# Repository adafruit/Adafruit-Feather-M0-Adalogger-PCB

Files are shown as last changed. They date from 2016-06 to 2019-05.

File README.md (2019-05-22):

## Adafruit Feather M0 Adalogger PCB
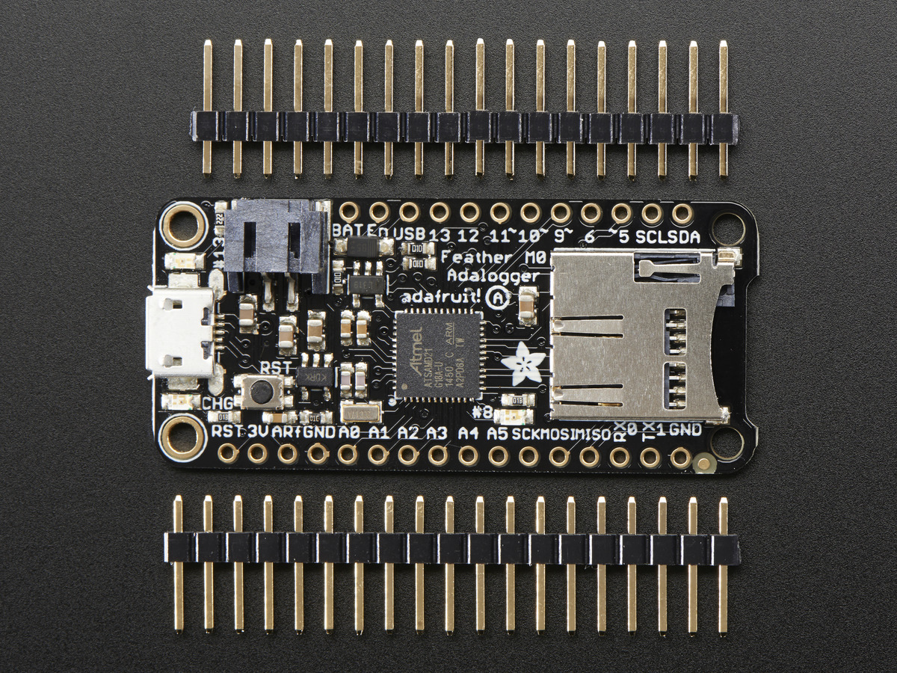
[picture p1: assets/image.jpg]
<a href="http://www.adafruit.com/products/2796"><br/>
Click here to purchase one from the Adafruit shop</a>

This is the Adafruit Feather M0 Adalogger - our take on an 'all-in-one' Cortex M0 datalogger (or data-reader) with built in USB and battery charging. Its an Adafruit Feather M0 with a microSD holder ready to rock! We have other boards in the Feather family, check'em out here

At the Feather M0's heart is an ATSAMD21G18 ARM Cortex M0 processor, clocked at 48 MHz and at 3.3V logic, the same one used in the new Arduino Zero. This chip has a whopping 256K of FLASH (8x more than the Atmega328 or 32u4) and 32K of RAM (16x as much)! This chip comes with built in USB so it has USB-to-Serial program & debug capability built in with no need for an FTDI-like chip.

PCB files for the Adafruit Feather M0 Adalogger. The format is EagleCAD schematic and board layout
- https://www.adafruit.com/product/2796

### License

Adafruit invests time and resources providing this open source design, please support Adafruit and open-source hardware by purchasing products from [Adafruit](https://www.adafruit.com)!

All text above must be included in any redistribution

Designed by Limor Fried/Ladyada for Adafruit Industries.
Creative Commons Attribution/Share-Alike, all text above must be included in any redistribution. 
See license.txt for additional information.

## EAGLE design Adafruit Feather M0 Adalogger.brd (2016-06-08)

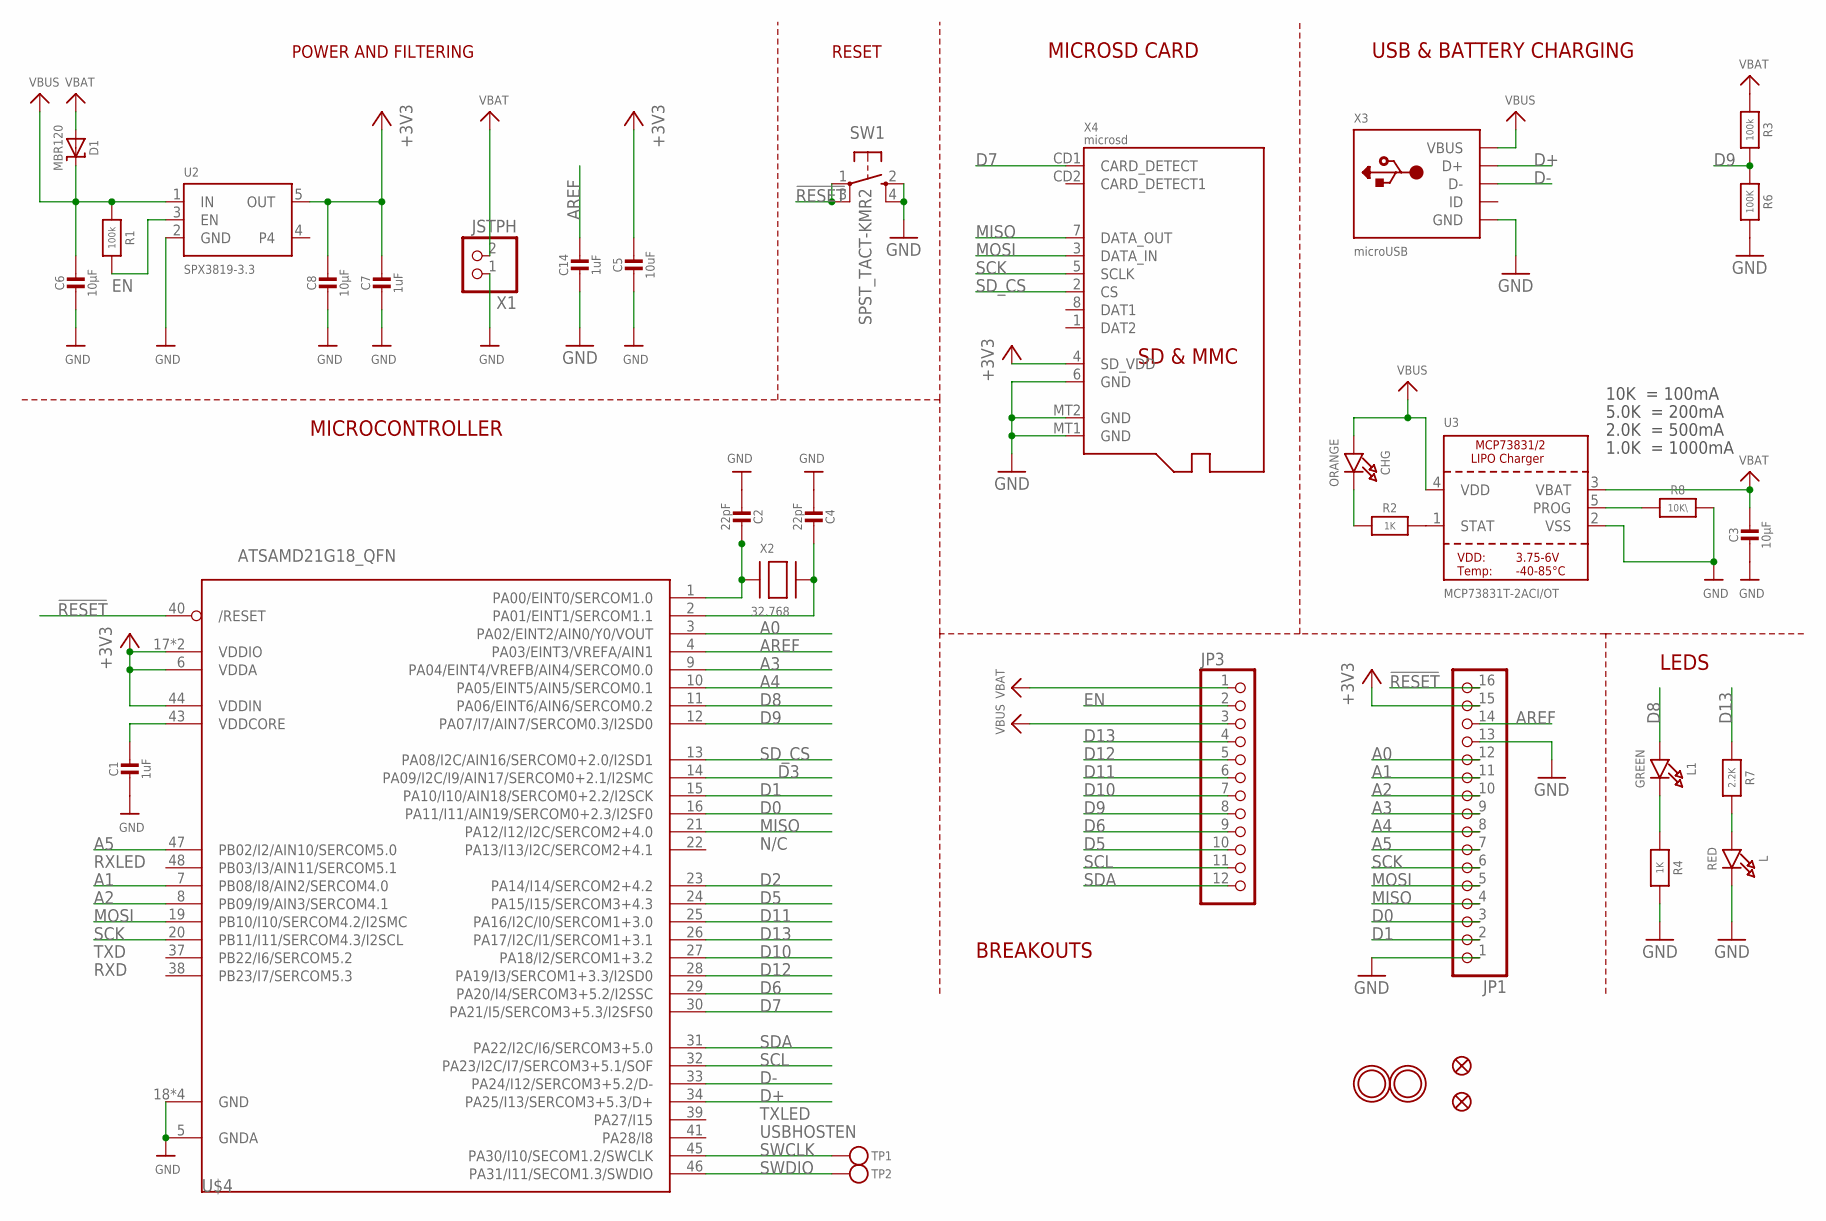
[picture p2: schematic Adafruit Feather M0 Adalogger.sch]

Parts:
C1, C7, C14: 1uF; 0603-NO
C2, C4: 22pF; 0603-NO
C3, C6, C8: 10µF; 0805-NO
C5: 10uF; 0805-NO
CHG: ORANGE; CHIPLED_0805_NOOUTLINE
D1: MBR120; SOD-123
JP1: HEADER-1X16ROUND; 1X16_ROUND
JP3: HEADER-1X12; 1X12_ROUND
L: RED; CHIPLED_0805_NOOUTLINE
L1: GREEN; CHIPLED_0805_NOOUTLINE
R1, R3: 100k; 0603-NO
R2, R4: 1K; 0603-NO
R6: 100K; 0603-NO
R7: 2.2K; 0603-NO
R8: 10K\; 0603-NO
SW1: SPST_TACT-KMR2; KMR2
TP1, TP2: TESTPOINTROUND1.5MM; TESTPOINT_ROUND_1.5MM
U2: SPX3819-3.3; SOT23-5
U3: MCP73831T-2ACI/OT; SOT23-5
U$4: ATSAMD21G18_QFN; TQFN48_7MM
U$31, U$32: MOUNTINGHOLE2.5; MOUNTINGHOLE_2.5_PLATED
U$34, U$35: FIDUCIAL""; FIDUCIAL_1MM
X1: JSTPH; JSTPH2
X2: 32.768; XTAL3215
X3: microUSB; 4UCONN_20329_V2
X4: microsd; MICROSD

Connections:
!RESET: JP1.16, SW1.1, SW1.3 (P1), U$4.40 (/RESET)
+3V3: C5.1, C7.1, C8.1, JP1.15, U2.5 (OUT), U$4.6 (VDDA), U$4.17 (VDDIO), U$4.36 (VDDIO), U$4.44 (VDDIN), X4.4 (SD_VDD)
A0: JP1.12, U$4.3 (PA02/EINT2/AIN0/Y0/VOUT)
A1: JP1.11, U$4.7 (PB08/I8/AIN2/SERCOM4.0)
A2: JP1.10, U$4.8 (PB09/I9/AIN3/SERCOM4.1)
A3: JP1.9, U$4.9 (PA04/EINT4/VREFB/AIN4/SERCOM0.0)
A4: JP1.8, U$4.10 (PA05/EINT5/AIN5/SERCOM0.1)
A5: JP1.7, U$4.47 (PB02/I2/AIN10/SERCOM5.0)
AREF: C14.1, JP1.14, U$4.4 (PA03/EINT3/VREFA/AIN1)
D0: JP1.3, U$4.16 (PA11/I11/AIN19/SERCOM0+2.3/I2SF0)
D1: JP1.2, U$4.15 (PA10/I10/AIN18/SERCOM0+2.2/I2SCK)
D2: U$4.23 (PA14/I14/SERCOM2+4.2)
D3: U$4.14 (PA09/I2C/I9/AIN17/SERCOM0+2.1/I2SMC)
D5: JP3.10, U$4.24 (PA15/I15/SERCOM3+4.3)
D6: JP3.9, U$4.29 (PA20/I4/SERCOM3+5.2/I2SSC)
D7: U$4.30 (PA21/I5/SERCOM3+5.3/I2SFS0), X4.CD1 (CARD_DETECT)
D8: L1.A, U$4.11 (PA06/EINT6/AIN6/SERCOM0.2)
D9: JP3.8, R3.2, R6.1, U$4.12 (PA07/I7/AIN7/SERCOM0.3/I2SD0)
D10: JP3.7, U$4.27 (PA18/I2/SERCOM1+3.2)
D11: JP3.6, U$4.25 (PA16/I2C/I0/SERCOM1+3.0)
D12: JP3.5, U$4.28 (PA19/I3/SERCOM1+3.3/I2SD0)
D13: JP3.4, R7.1, U$4.26 (PA17/I2C/I1/SERCOM1+3.1)
D+: U$4.34 (PA25/I13/SERCOM3+5.3/D+), X3.D+
D-: U$4.33 (PA24/I12/SERCOM3+5.2/D-), X3.D-
EN: JP3.2, R1.2, U2.3 (EN)
GND: C1.2, C2.2, C3.2, C4.2, C5.2, C6.2, C7.2, C8.2, C14.2, JP1.1, JP1.13, L.C, R4.2, R6.2, R8.2, SW1.2 (S), SW1.4 (S1), U2.2 (GND), U3.2 (VSS), U$4.5 (GNDA), U$4.18 (GND), U$4.35 (GND), U$4.42 (GND), U$4.THERMAL (GND), X1.1, X3.BASE@1 (GND), X3.BASE@2 (GND), X3.GND, X3.SPRT@1 (GND), X3.SPRT@2 (GND), X3.SPRT@3 (GND), X3.SPRT@4 (GND), X4.6 (GND), X4.MT1 (GND), X4.MT2 (GND)
MISO: JP1.4, U$4.21 (PA12/I12/I2C/SERCOM2+4.0), X4.7 (DATA_OUT)
MOSI: JP1.5, U$4.19 (PB10/I10/SERCOM4.2/I2SMC), X4.3 (DATA_IN)
unnamed: CHG.C, R2.1
unnamed: L.A, R7.2
unnamed: R2.2, U3.1 (STAT)
unnamed: R8.1, U3.5 (PROG)
unnamed: C2.1, U$4.1 (PA00/EINT0/SERCOM1.0), X2.P$1
unnamed: L1.C, R4.1
unnamed: C4.1, U$4.2 (PA01/EINT1/SERCOM1.1), X2.P$2
SCK: JP1.6, U$4.20 (PB11/I11/SERCOM4.3/I2SCL), X4.5 (SCLK)
SCL: JP3.11, U$4.32 (PA23/I2C/I7/SERCOM3+5.1/SOF)
SDA: JP3.12, U$4.31 (PA22/I2C/I6/SERCOM3+5.0)
SD_CS: U$4.13 (PA08/I2C/AIN16/SERCOM0+2.0/I2SD1), X4.2 (CS)
SWCLK: TP1.P$1, U$4.45 (PA30/I10/SECOM1.2/SWCLK)
SWDIO: TP2.P$1, U$4.46 (PA31/I11/SECOM1.3/SWDIO)
VBAT: C3.1, D1.A, JP3.1, R3.1, U3.3 (VBAT), X1.2
VBUS: C6.1, CHG.A, D1.C, JP3.3, R1.1, U2.1 (IN), U3.4 (VDD), X3.VBUS
VDDCORE: C1.1, U$4.43 (VDDCORE)

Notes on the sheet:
POWER AND FILTERING
RESET
10K = 100mA
5.0K = 200mA
2.0K = 500mA
1.0K = 1000mA
N/C
TXLED
USBHOSTEN
RXLED
TXD
RXD
USB & BATTERY CHARGING
MICROSD CARD
BREAKOUTS
LEDS
MICROCONTROLLER

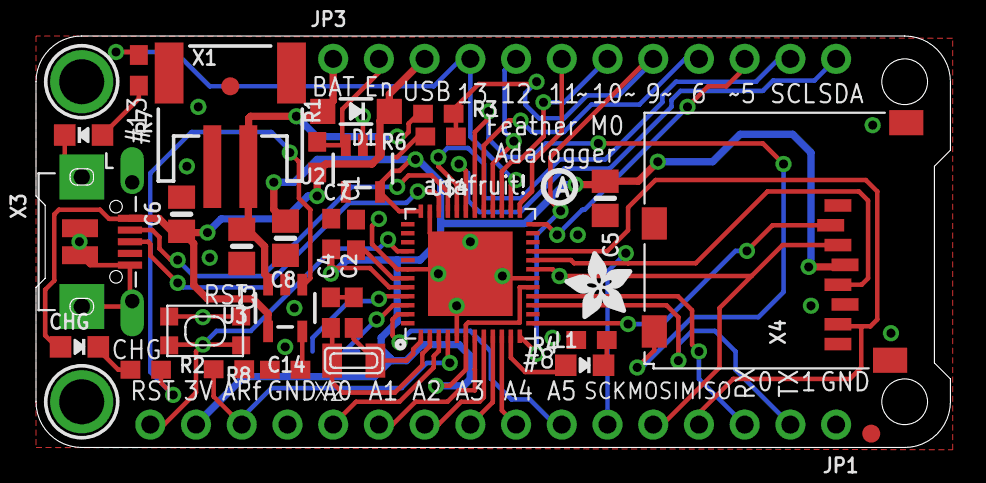
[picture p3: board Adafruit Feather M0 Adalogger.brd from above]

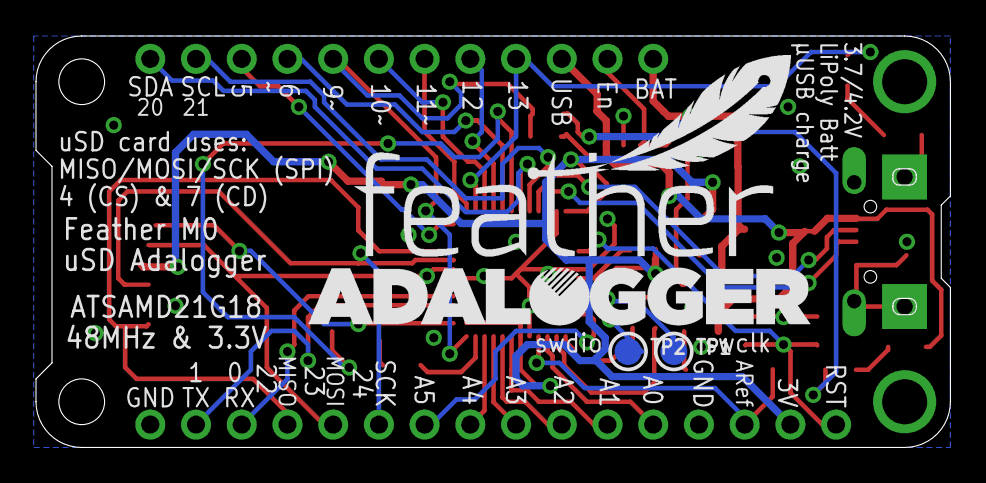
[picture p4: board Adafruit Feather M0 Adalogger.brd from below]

Board: 2 copper layers, 50.8 x 22.9 mm, 40 parts (4 on the bottom side), 42 nets.

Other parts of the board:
U$7: ADAFRUIT_3.5MM
U$9: PCBFEAT-REV-040
U$13: FEATHERLOGO
U$14: ADALOGGER_LOGO

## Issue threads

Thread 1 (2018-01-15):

wont compile "analogSerial example

sguwi, 2018-01-15:
Try to load simple "AnalogReadSerial example but keep getting:

 java.io.IOException: Cannot run program "{runtime.tools.bossac-1.7.0.path}/bossac.exe": CreateProcess error=2, Can't find the file.

I have installed JRE and JDK and JAVA_HOME

 /*AnalogReadSerial

  Reads an analog input on pin 0, prints the result to the Serial Monitor.
  Graphical representation is available using Serial Plotter (Tools > Serial Plotter menu).
  Attach the center pin of a potentiometer to pin A0, and the outside pins to +5V and ground.

  This example code is in the public domain.

  http://www.arduino.cc/en/Tutorial/AnalogReadSerial
*/

// the setup routine runs once when you press reset:
void setup() {
  // initialize serial communication at 9600 bits per second:
  Serial.begin(9600);
}

// the loop routine runs over and over again forever:
void loop() {
  // read the input on analog pin 0:
  int sensorValue = analogRead(A0);
  // print out the value you read:
  Serial.println(sensorValue);
  delay(1);        // delay in between reads for stability
}

ladyada, 2018-01-15:
hiya - this is the github for the PCB
tech support for adafruit products is handled in the forums, thx :)

Closed 2018-01-15.

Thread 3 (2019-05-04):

Grounding of filtering caps on VDDCORE and +3V3

nysfred, 2019-05-04:
When I looked at PCB layout, I don't see caps C1 and C7 connected to GND.
Moreover, in schematics I don't see VDDCore connected to anything but the cap.

Is it a mistake or something I don't understand?

ladyada, 2019-05-05:
there's a ground plane that you have to fill to see GND. it is correct

nysfred, 2019-05-05:
Sorry for my ignorance, first time I am using Eagle. Have you done it in the file and it is just a question of displaying it or it shall be done just before manufacturing?

Thanks anyway for your work!

Closed 2019-05-05.

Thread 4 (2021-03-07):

Hardware revision request: microSD power control

adamgarbo, 2021-03-07:
Hi @ladyada,

The Adafruit Feather M0 Adalogger represents a valuable tool for data collection in the natural sciences. However, its biggest drawback is that power to the microSD card can not be disabled. As you know, the current draw of microSD cards can be significant, even when idle, and low-power operation is critical for many scientific applications.

This feature has been requested many times on the Adafruit forums. Would you consider adding power control circuitry to allow the Adalogger to disable power to the microSD?

Cheers,
Adam

ladyada, 2021-03-07:
this board isnt likely to be revised, however maybe some other board will!

Closed 2021-03-07.

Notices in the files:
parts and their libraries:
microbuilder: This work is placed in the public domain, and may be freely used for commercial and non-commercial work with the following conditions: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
